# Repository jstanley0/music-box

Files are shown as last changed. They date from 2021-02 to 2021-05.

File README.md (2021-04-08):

# music-box
Chiptune music player featuring SN76489 and ATtiny861/ATtiny84

music-box in action

## Overview
This project grew out of a Wikipedia surfing session. In reading about the computers of my childhood,
I came across an article about the TI SN76489 sound chip, used by two of the machines I used as a kid
(the TI 99/4A and IBM PCjr). I wondered if you can readily buy this IC, and if you can talk to it
reasonably easily with modern hardware. The answer to both questions is yes!

## How it works
All eight pins of PORTA are connected to the SN76489's data lines. PB4 connects to /WE and latches
a value to the chip. PB5 (CLKO) outputs the ATtiny861's clock signal directly to the sound chip's
clock input. /OE is permanently tied low and READY is ignored. I'm not sharing a bus with anything 
else...

The MCU firmware plays music from an array of bytes stored in program memory (in songs.c). It's a
very simple binary format with three one-byte commands that play a note, play a noise, and sleep.
To keep things simple, I ignore note-off events and simply make each note decay at a constant
linear rate after it is struck. Much like an actual music box!

## Loading music
util/process_midi_file.cpp will take a MIDI file and output a set of arrays for songs.c. It makes
use of [light-midi-parser](https://github.com/imhcyx/light-midi-parser) as a submodule.

## ATtiny84
This project can also be built for the ATtiny84, via `make -e DEVICE=attiny84`.
With this target there will be just one blinking light, rather than one per channel. See main.c for wiring differences.

## See also
I've also created a more elaborate stereo two-chip player using the Raspberry Pi Pico, [pico-player](https://github.com/jstanley0/pico-player).

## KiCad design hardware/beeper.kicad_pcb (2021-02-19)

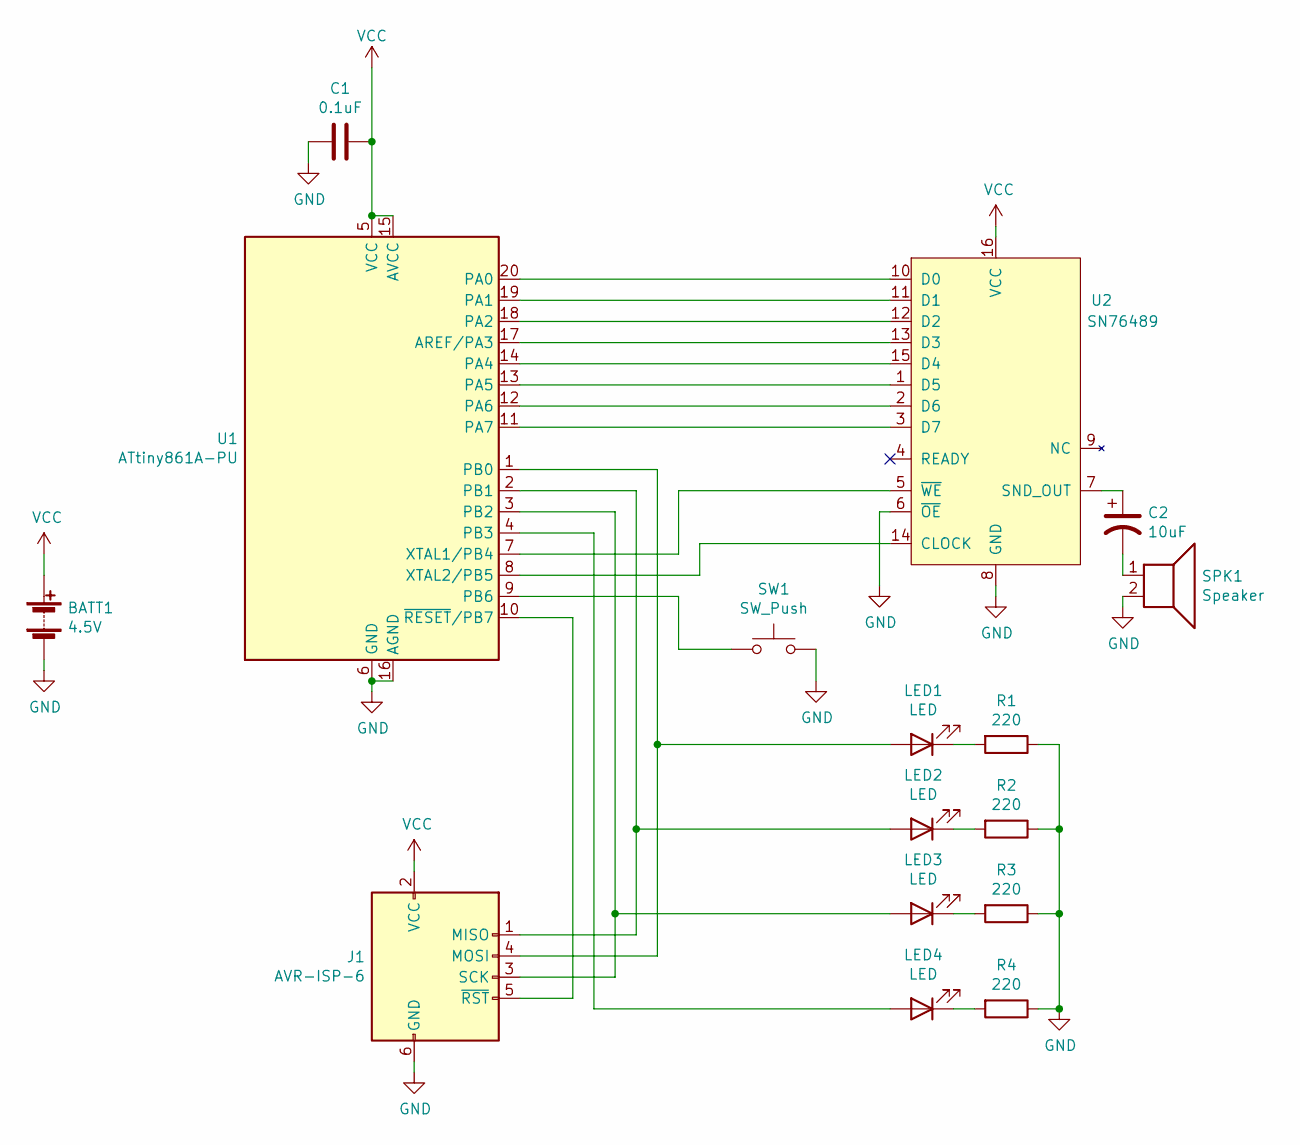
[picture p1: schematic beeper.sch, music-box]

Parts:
BATT1: 4.5V; PinHeader_1x02_P2.54mm_Vertical
C1: 0.1uF; C_Disc_D3.0mm_W1.6mm_P2.50mm
C2: 10uF; CP_Radial_D6.3mm_P2.50mm
J1: AVR-ISP-6; PinHeader_2x03_P2.54mm_Vertical
LED1, LED2, LED3, LED4: LED; LED_D5.0mm_Clear
R1, R2, R3, R4: 220; R_Axial_DIN0204_L3.6mm_D1.6mm_P1.90mm_Vertical
SPK1: Speaker; PinHeader_1x02_P2.54mm_Vertical
SW1: SW_Push; SW_Tactile_Straight_KSA0Axx1LFTR
U1: ATtiny861A-PU; DIP-20_W7.62mm
U2: SN76489; DIP-16_W7.62mm

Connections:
GND: BATT1.2 (-), C1.2, J1.6 (GND), R1.1, R2.1, R3.1, R4.1, SPK1.2, SW1.2, U1.6 (GND), U1.16 (AGND), U2.6 (~OE), U2.8 (GND)
unnamed: C2.1, U2.7 (SND_OUT)
unnamed: C2.2, SPK1.1
unnamed: J1.1 (MISO), LED2.2 (A), U1.2 (PB1)
unnamed: J1.3 (SCK), LED3.2 (A), U1.3 (PB2)
unnamed: J1.4 (MOSI), LED1.2 (A), U1.1 (PB0)
unnamed: J1.5 (~RST), U1.10 (~RESET~/PB7)
unnamed: LED1.1 (K), R1.2
unnamed: LED2.1 (K), R2.2
unnamed: LED3.1 (K), R3.2
unnamed: LED4.1 (K), R4.2
unnamed: LED4.2 (A), U1.4 (PB3)
unnamed: SW1.1, U1.9 (PB6)
unnamed: U1.7 (XTAL1/PB4), U2.5 (~WE)
unnamed: U1.8 (XTAL2/PB5), U2.14 (CLOCK)
unnamed: U1.11 (PA7), U2.3 (D7)
unnamed: U1.12 (PA6), U2.2 (D6)
unnamed: U1.13 (PA5), U2.1 (D5)
unnamed: U1.14 (PA4), U2.15 (D4)
unnamed: U1.17 (AREF/PA3), U2.13 (D3)
unnamed: U1.18 (PA2), U2.12 (D2)
unnamed: U1.19 (PA1), U2.11 (D1)
unnamed: U1.20 (PA0), U2.10 (D0)
VCC: BATT1.1 (+), C1.1, J1.2 (VCC), U1.5 (VCC), U1.15 (AVCC), U2.16 (VCC)

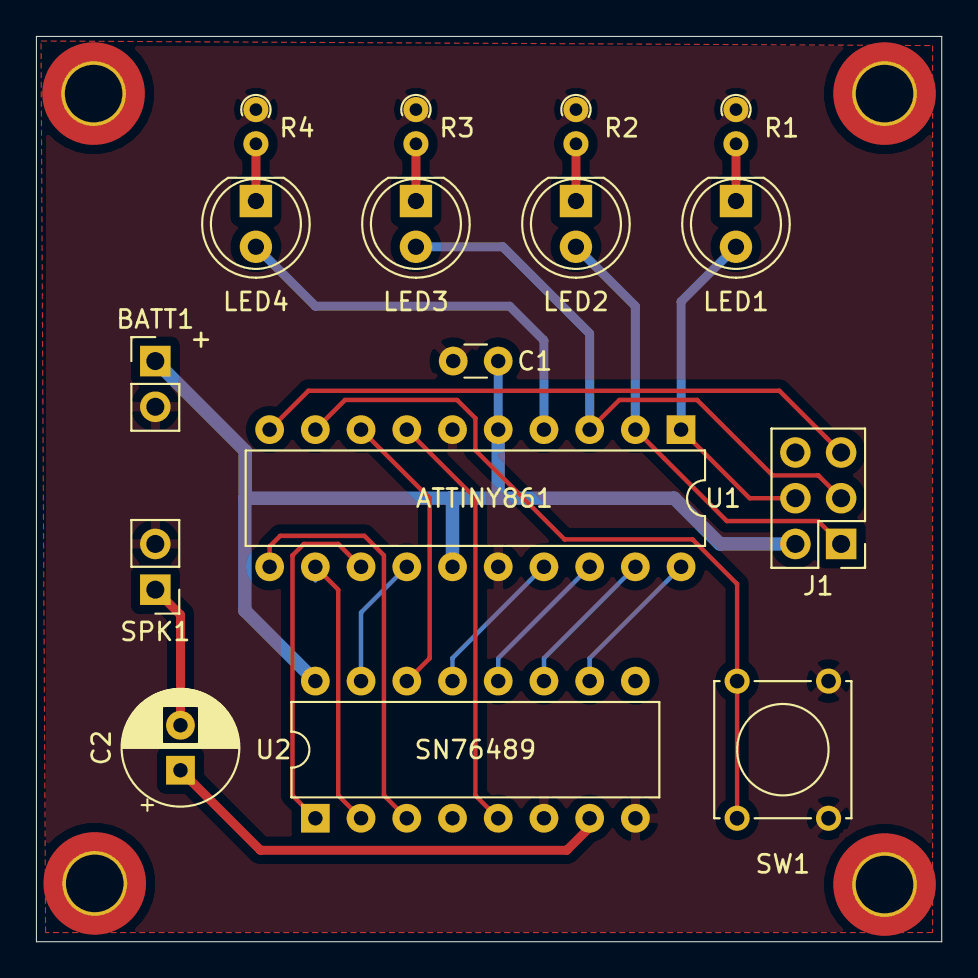
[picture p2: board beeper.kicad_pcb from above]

Board: 2 copper layers, 50.3 x 50.3 mm, 17 parts (0 on the bottom side), 24 nets.

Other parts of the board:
\: MountingHole_3.2mm_M3_ISO7380_Pad_TopBottom

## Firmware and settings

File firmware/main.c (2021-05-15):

// attiny861 / TI SN76489 music box
// (c) 2021 by Jeremy Stanley

// port assignments (ATtiny861 -> TI SN76489):
// PA0..PA7 -> D7..D0
// PB4 -> /WE
// PB5 -> CLOCK (via CKOUT fuse)

// other pin assignments:
// PB0..3 -> blinkenlights
// PB6 -> tac switch

// alternatively this can be compiled for ATtiny84
// using `make -e DEVICE=attiny84`
// which uses the following port assignments:
// PA0..PA7 -> D7..D0
// PB1 -> /WE
// PB2 -> CLOCK
// PB0 -> blinkenlight (just one)

#include <avr/io.h>
#include <avr/pgmspace.h>
#include <avr/sleep.h>
#include <avr/interrupt.h>
#include <util/delay.h>

#include "songs.h"
const uint8_t *const songs[] PROGMEM = { st_elsewhere, lament, macgyver, brooklet, quantum_leap, nervous, hogans_heroes, charlie_brown };
const uint8_t NUM_SONGS = sizeof(songs) / sizeof(songs[0]);

#ifdef __AVR_ATtiny84__
#define WE_BIT PORTB1
#else
#define WE_BIT PORTB4
#endif

// hi-hat, ride cymbal, etc. don't play at full volume
#define ATTENUATED_PERCUSSION_LEVEL 4

void init_clock()
{
  // change clock divider from /8 to /4 so we run at 2MHz,
  // which is an acceptable clock frequency for the SN76489
  // (at 4MHz, we lose too much low range, and at 1MHz, high notes get out of tune)
  CLKPR = (1 << CLKPCE);  // Clock Prescaler Change Enable - this part is necessary
  CLKPR = (1 << CLKPS1);  // 4x divider
}

void init_io()
{
  DDRA  = 0xff;
#ifdef __AVR_ATtiny84__
  DDRB  = 0b00000111;
  PORTB = (1 << WE_BIT);
#else
  DDRB  = 0b00111111;
  PORTB = (1 << PORTB6) | (1 << WE_BIT);
#endif
}

void send_byte(uint8_t byte)
{
  PORTA = byte;
  PORTB &= ~(1 << WE_BIT);
  _delay_us(16);  // 32 clock cycles at 2MHz
  PORTB |= (1 << WE_BIT);
}

void send_frequency(uint8_t voice, uint16_t freq)
{
  send_byte(0x80U | (voice << 5) | (freq & 0x0F));
  send_byte(freq >> 4);
}

void send_noise(uint8_t n)
{
  send_byte(0xE0U | n);
}

void send_attenuation(uint8_t voice, uint8_t atten)
{
  send_byte(0x90U | (voice << 5) | atten);
}

uint8_t playing_atten[4] = { 15, 15, 15, 15 };

#ifdef __AVR_ATtiny84__
volatile uint8_t OCR0A_buf = 0;

void update_blinkenlight()
{
  uint8_t blinkenlight = 0;
  for(uint8_t i = 0; i < 4; ++i) {
    blinkenlight += (63 >> playing_atten[i]);
  }
  OCR0A_buf = blinkenlight;
}
#else
static const uint8_t fade_table[16] PROGMEM = {254, 179, 125, 88, 61, 43, 30, 21, 15, 10, 7, 5, 4, 2, 1, 0};

volatile uint8_t OCR0A_buf = 0, OCR0B_buf = 0;
void set_led(uint8_t voice, uint8_t atten)
{
    static volatile uint8_t *intensity_reg[4] = { &OCR0A_buf, &OCR1A, &OCR0B_buf, &OCR1B };
    *intensity_reg[voice] = pgm_read_byte(&fade_table[playing_atten[voice]]);
}
#endif

void note(uint8_t note)
{
  // pick the quietest voice
  uint8_t v = 0;
  for(uint8_t i = 1; i < 3; ++i) {
    if (playing_atten[i] > playing_atten[v])
      v = i;
  }

  // play the note!
  playing_atten[v] = 0;
  send_frequency(v, pgm_read_word(&note_table[note]));
  send_attenuation(v, 0);
#ifndef __AVR_ATtiny84__
  set_led(v, 0);
#endif
}

void noise(uint8_t n, uint8_t initial_attenuation)
{
  playing_atten[3] = initial_attenuation;
  send_noise(n);
  send_attenuation(3, initial_attenuation);
#ifndef __AVR_ATtiny84__
  set_led(3, 0);
#endif
}

void decay()
{
  for(uint8_t i = 0; i < 3; ++i) {
    if (playing_atten[i] < 15) {
      send_attenuation(i, ++playing_atten[i]);
#ifndef __AVR_ATtiny84__
      set_led(i, playing_atten[i]);
#endif
    }
  }
}

void decay_noise()
{
  if (playing_atten[3] < 15) {
    send_attenuation(3, ++playing_atten[3]);
#ifndef __AVR_ATtiny84__
    set_led(3, playing_atten[3]);
#endif
  }
}

void silence()
{
  for(int i = 0; i < 4; ++i)
    send_attenuation(i, 15);
}

volatile uint8_t g_Tick = 0;

#ifdef __AVR_ATtiny84__

ISR(TIM0_COMPA_vect)
{
  // LED off
  PORTB &= 0b11111110;
}

ISR(TIM0_OVF_vect)
{
  // LED on, maybe
  OCR0A = OCR0A_buf;
  if (OCR0A_buf > 0)
    PORTB |= 1;

  // music heartbeat
  g_Tick += 1;
}

#else

// LED 1 off
ISR(TIMER0_COMPA_vect)
{
  PORTB &= 0b11111110;
}

// LED 3 off
ISR(TIMER0_COMPB_vect)
{
  PORTB &= 0b11111011;
}

ISR(TIMER0_OVF_vect)
{
  // LED 1 on, maybe
  OCR0A = OCR0A_buf;
  if (OCR0A_buf > 0)
    PORTB |= 0b001;

  // LED 3
  OCR0B = OCR0B_buf;
  if (OCR0B_buf > 0)
    PORTB |= 0b100;

  // music heartbeat
  g_Tick += 1;
}

#endif

void sleep_one_tick()
{
  while (g_Tick == 0) {
    set_sleep_mode(SLEEP_MODE_IDLE);
    sleep_enable();
    sleep_cpu();
  }
  g_Tick -= 1;
}

void init_interrupts()
{
#ifdef __AVR_ATtiny84__
  // one LED with software PWM
  TCCR0A = 0;                            // normal mode, 8-bit
  TCCR0B = (1 << CS01) | (1 << CS00);    // 1/64 prescaler
  TIMSK0 = (1 << OCIE0A) | (1 << TOIE0); // enable COMPA and OVF vectors
#else
  // this is gonna be a bit hacky because THERE ARE FOUR LIGHTS.

  // two of them (LEDs 2 and 4) are easy: they're on OC1A and OC1B pins, so we can use fast PWM mode
  TCCR1A = (1 << COM1A1) | (1 << COM1B1) | (1 << PWM1A) | (1 << PWM1B);
  // set prescaler 1/64: 2MHz / 256 / 64 = 122Hz, a perfectly cromulent refresh rate
  TCCR1B = (1 << CS12) | (1 << CS11) | (1 << CS10);

  // we can't use the third PWM channel (because its pin is shared with CLKO)
  // and there is no fourth PWM channel anyway
  // so we'll use timer0 for LEDs 1 and 3
  TCCR0A = 0;                            // normal mode, 8-bit
  TCCR0B = (1 << CS01) | (1 << CS00);    // 1/64 prescaler
  TIMSK |= (1 << OCIE0A) | (1 << OCIE0B) | (1 << TOIE0); // enable COMPA, COMPB, and overflow vectors
#endif
}

void play_song(uint8_t song_num)
{
  const uint8_t *PROGMEM song_data = (uint8_t *)pgm_read_word(&songs[song_num]);
  uint16_t song_pos = 0;
  uint8_t wait_cycles = 50;
  uint8_t decay_cycles = 0;
  uint8_t noise_cycles = 0;
  int8_t noise_target = 0;
  int8_t fade_out = 0;

  for(;;)
  {
    sleep_one_tick();

#ifdef __AVR_ATtiny84__
    update_blinkenlight();
#else
    if (0 == (PINB & (1 << PB6))) {
        fade_out = 100;
    }
#endif

    if (++decay_cycles == 6) {
      decay_cycles = 0;
      decay();
    }
    if (++noise_cycles == noise_target) {
      noise_cycles = 0;
      decay_noise();
    }

    if (fade_out > 0) {
        if (--fade_out == 0)
            break;
        else
            continue;
    }

    if (wait_cycles > 0) {
      --wait_cycles;
      continue;
    }

    // keep executing song commands until we hit a delay or end of song
    while(wait_cycles == 0) {
      uint8_t song_cmd = pgm_read_byte(&song_data[song_pos]);
      uint8_t noise_atten;
      switch(song_cmd & 0xC0) {
      case 0: // note
        note(song_cmd);
        break;
      case 0x40: // delay
        wait_cycles = song_cmd & 0x3F;
        break;
      case 0x80: // noise
        //  7  6  5  4  3  2  1  0
        //  1  0 A0 S1 S0 N2 N1 N0
        noise_target = 1 + ((song_cmd & 0x18) >> 3);
        noise_atten = (song_cmd & 0x20);
        noise_cycles = 0;
        noise(song_cmd & 0x07, noise_atten ? ATTENUATED_PERCUSSION_LEVEL : 0);
        break;
      case 0xC0: // end song
        fade_out = 100;
      }
      ++song_pos;
    }
  }
}

int main(void)
{
  init_clock();
  init_io();
  silence();
  init_interrupts();
  sei();

  uint8_t song_num = 0;
  for(;;) {
    play_song(song_num);
    if (++song_num >= NUM_SONGS)
        song_num = 0;
  }
}

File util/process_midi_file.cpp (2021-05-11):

#include <iostream>
#include <unistd.h>
#include <math.h>
#include <stdlib.h>
#include <string.h>
#include <vector>
#include <set>
#include <cstdarg>
extern "C" {
#include "midi.h"
}

const double AVR_CLOCK = 2000000.0;
// the lowest achievable frequency is AVR_CLOCK / 32768 or 61Hz, just below B1
const int LOWEST_NOTE = 35; // B1
const int HIGHEST_NOTE = LOWEST_NOTE + 63; // D7

const int POLYPHONY = 3;
const int US_PER_TICK = (1000000.0 * 256 * 64) / AVR_CLOCK; // (8192 microseconds at 2MHz)

// noise types
const int HIGH_PERIODIC = 0, MID_PERIODIC = 1, LOW_PERIODIC = 2,
          HIGH_WHITE = 4, MID_WHITE = 5, LOW_WHITE = 6;

struct Event {
  int delay;
  std::set<int> notes;
  std::set<int> noise;

  explicit Event(int _delay = 0) : delay(_delay) {}
};

class Encoder {
  std::vector<Event> song_data;

  std::ostream &os;
  int min_note, max_note;

  void write1(int data) {
    os << "0x" << std::hex << data << ",";
  }

  int process_note(int note) {
    // with 6 bits we are limited to a bit more than 5 octaves
    // so we'll just shift notes that are out of range into an octave we have
    while(note < LOWEST_NOTE)
      note += 12;
    while(note > HIGHEST_NOTE)
      note -= 12;
    return note - LOWEST_NOTE;
  }

  void write_note(int note) {
    note = process_note(note);
    write1(note);
  }

  void write_noise(int noise) {
    write1(0x80 | noise);
  }

  void write_delay(int cs) {
    while(cs > 63) {
      write1(0x7F);
      cs -= 63;
    }
    if (cs > 0)
      write1(0x40 | cs);
  }

  bool percussion_hit(const std::set<int> &perc, int dummy ...) {
    va_list args;
    va_start(args, dummy);
    int i = 0;
    while((i = va_arg(args, int)) > 0) {
      if (perc.end() != perc.find(i))
        return true;
    }
    return false;
  }

  // noise (N == noise type, A = attenuated; S = sustain cycles - 1)
  //  7  6  5  4  3  2  1  0
  //  1  0 A0 S1 S0 N2 N1 N0
  int noise_code(int noise_type, int sustain_add = 0, bool attenuated = false) {
    return (sustain_add << 3) | noise_type | (attenuated ? 0x20 : 0);
  }

  int map_noise(const std::set<int> &perc) {
    // since we can only hear one noise at a time, these are prioritized
    if (percussion_hit(perc, 0, 49, 57, -1))
      return noise_code(HIGH_WHITE, 3, true); // crash cymbal
    if (percussion_hit(perc, 0, 51, 59, -1))
      return noise_code(MID_WHITE, 2, true); // ride cymbal
    if (percussion_hit(perc, 0, 37, 38, 39, 40, 52, 55, -1))
      return noise_code(HIGH_WHITE); // snare-ish
    else if (percussion_hit(perc, 0, 35, 36, 41, 45, -1))
      return noise_code(LOW_WHITE); // bass drum-ish
    else if (percussion_hit(perc, 0, 47, 61, 64, 66, 68, 77, -1))
      return noise_code(LOW_PERIODIC); // low tom, etc.
    else if (percussion_hit(perc, 0, 48, 60, 62, 63, 65, 67, 76, -1))
      return noise_code(MID_PERIODIC); // mid tom, etc.
    if (percussion_hit(perc, 0, 50, 56, 71, 72, 80, 81, -1))
      return noise_code(HIGH_PERIODIC); // hi tom, etc.
    else if (percussion_hit(perc, 0, 46, 53, 54, 55, 58, 70, -1))
      return noise_code(HIGH_WHITE, 2, true); // open hi-hat, misc
    else if (percussion_hit(perc, 0, 42, 44, -1))
      return noise_code(MID_WHITE, 0, true); // closed hi-hat
    return -1;
  }

  void write_note_table() {
    os << "const uint16_t note_table[64] PROGMEM = {";
    for(int i = 0; i < 64; ++i) {
      os << (int)round(AVR_CLOCK / (32 * 440.0 * pow(2, ((i + LOWEST_NOTE) - 69.0) / 12))) << ",";
    }
    os << "};\n";
  }

  void write_song_data() {
    process_last_event();
    song_data[0].delay = 0; // skip initial delay. in some songs, there's quite a bit of it
    os << "const uint8_t song_data[] PROGMEM = {";
    for(auto&& evt : song_data) {
      if (evt.delay > 0)
        write_delay(evt.delay);
      for(auto note : evt.notes)
        write_note(note);
      if (!evt.noise.empty()) {
        int noise = map_noise(evt.noise);
        if (noise >= 0)
          write_noise(noise);
      }
    }
    os << "0xff};\n";
  }

  void ensure_event() {
    if (song_data.empty()) {
      song_data.emplace_back(0);
    }
  }

  void process_last_event() {
    if (song_data.empty())
      return;
    auto &event = song_data.back();

    // if there are too many notes to strike at once, cull some of them
    // leaving the highest and lowest notes alone
    while(event.notes.size() > POLYPHONY) {
      event.notes.erase(std::next(event.notes.begin()));
    }
  }

public:
  Encoder(std::ostream &s = std::cout) : os(s), min_note(128), max_note(0) {
  }

  void log_delay(int cs) {
    if (!song_data.empty() && song_data.back().notes.empty()) {
      song_data.back().delay += cs;
    } else {
      process_last_event();
      song_data.emplace_back(cs);
    }
  }

  void log_note(int channel, int note, int velocity) {
    if (velocity == 0)
      return; // some MIDI files use note-on events with velocity 0 as note-off events

    ensure_event();
    if (channel == 9) {
      song_data.back().noise.insert(note);
    } else {
      if (note < min_note) min_note = note;
      if (note > max_note) max_note = note;
      song_data.back().notes.insert(note);
    }
  }

  void write_song() {
    write_note_table();
    write_song_data();
  }

  ~Encoder() {
    std::cerr << "encoder stats:\n";
    std::cerr << "note range " << min_note << " - " << max_note << " (" << max_note - min_note + 1 << ")\n";
  }
};

int main(int argc, char* argv[]) {
  if (argc < 2) {
    std::cerr << "Usage: process_midi_file file.mid [transpose_semitones]" << std::endl;
    return 1;
  }
  int transpose = 0;
  if (argc >= 3)
    transpose = atoi(argv[2]);

  midi_file *midi = midi_open_file(argv[1]);
  if (!midi) {
    std::cerr << "Failed to open file " << argv[1] << std::endl;
    return 1;
  }

  midi_trks *trks = midi_parse_tracks(midi);
  if (!trks) {
    std::cerr << "Failed to parse MIDI file" << std::endl;
    return 1;
  }

  midi_combine_tracks(trks);
  midi_convert_abstime(trks);

  midi_hdr hdr;
  midi_get_header(midi, &hdr);

  int tempo = 500000;
  int last_timestamp = 0;

  Encoder encoder;
  for(midi_evt_node *node = trks->trk[0]; node != NULL; node = node->next) {
    int64_t timestamp_us = ((int64_t)node->time * tempo) / hdr.division;
    int timestamp = timestamp_us / US_PER_TICK;
    if (timestamp > last_timestamp) {
      encoder.log_delay(timestamp - last_timestamp);
      last_timestamp = timestamp;
    }
    switch(node->evt) {
    case midi_meta_evt:
      if (node->meta == midi_set_tempo) {
        tempo = node->param1;
      }
      break;
    case midi_noteon:
      encoder.log_note(node->chan, node->param1 + transpose, node->param2);
      break;
    }
  }
  encoder.write_song();
  midi_free_tracks(trks);
  midi_close(midi);
  return 0;
}

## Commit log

2021-01-25 on second thought, I don't think this is necessary
    we may spend upwards of 100us talking to the sound chip but that
    isn't long enough to cause noticeable glitches in the blinkenlight
    [main.c]
2021-01-25 delay for half a second before starting
    to avoid stuttering as the power switch is engaged
    [main.c]
2021-01-26 add percussion on noise channel
    noise decays faster than notes, and actually doesn't sound
    too bad
    the mapping in the midi processor needs some experimentation,
    clearly
    [main.c, process_midi_file.cpp]
2021-01-26 flesh out percussion a bit
    also, with percussion in the mix, the blinkenlight PWM was
    glitching. ISR_NOBLOCK fixes it
    [main.c, process_midi_file.cpp]
2021-02-15 schematic and PCB
    ... for a slightly different project (using ATTiny861 and *four*
    blinkenlights). I haven't updated the firmware to match this yet.
    but I have sent out for PCB manufacture...
    [beeper.kicad_pcb, beeper.sch]
2021-02-19 shorter traces
    [beeper.kicad_pcb, beeper.sch]
2021-03-13 beginnings of ATtiny861 port
    it's functional, but I haven't implemented the per-voice
    blinkenlight PWM yet - they're all just flashing in unison
    naturally, there are three timer0 compare-match vectors,
    A, B, and D. there's a C register but no interrupt :|
    ... so I'll come up with something
2021-03-14 THERE ARE FOUR LIGHTS
    as part of the deal, I needed to change the player tick time
    so we can get it with a timer overflow. now instead of 10ms,
    it is 8.192ms. songs previously converted will play fast.
    also, both timers are doing LED PWM. song playing is moved
    out of the interrupt handler, which it never should have been in
    to begin with. I've tried to deal with the player code getting
    behind but I think there are still a few issues.
    [main.c, process_midi_file.cpp]
2021-03-14 update LED PWM only when it changes
2021-03-14 don't attenuate percussion _that_ much
    also sustain melodic notes longer to compensate for the faster
    timer-overflow heartbeat
2021-03-18 fix LED PWM glitch
    by double-buffering OCR0x changes
    also use a lookup table rather than a bit shift
    [main.c]
2021-03-18 update LED intensity immediately
    if we wait until decay begins, we never even use the highest
    brightness setting
2021-04-08 re-add ATtiny84 support
    this preserves a few bug fixes made since the ATtiny861 port
    compile with `make -e DEVICE=attiny84`
    be sure to `make clean` if you've already built the ATtiny861 binary
    because it will definitely not work on the ATtiny84
    [main.c]
